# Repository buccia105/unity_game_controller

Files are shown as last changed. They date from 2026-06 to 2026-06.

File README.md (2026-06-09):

# Unity Game Controller (Hardware Firmware)

This project contains the firmware for a physical game controller based on a microcontroller (ESP32/ESP8266), developed using **PlatformIO**. The device is designed to send input signals to a Unity application via network or serial protocol.

## Tech Stack
*   **Framework:** Arduino / PlatformIO 
*   **Supported Hardware:** ESP32 / ESP8266 
*   **Language:** C++ (C# on the Unity side) 

## Project Structure
*   `src/main.cpp`: Main firmware logic and physical input management.
*   `include/credentials.h`: Wi-Fi credentials configuration (do not publish!).
*   `platformio.ini`: Build environment and library configuration.
*   `lib/`: Local libraries specific to the controller.
*   `PCB/`: Files needed to create the pcb.
*   `SHOE/`: Files needed to print the shoe.

## Setup and Installation

### 1. Prerequisites
Ensure you have [Visual Studio Code](https://code.visualstudio.com/) installed with the **PlatformIO IDE** extension.

### 2. Credentials Management
The project uses a protection system for sensitive credentials:
1. Rename the file `include/template_credentials.h` to `include/credentials.h`.
2. Enter your Wi-Fi SSID and Password inside the file.
   *(Note: `credentials.h` is already included in `.gitignore` for security purposes)*.

### 3. Build and Upload
1. Connect the microcontroller to your computer via USB.
2. Click the arrow icon (→) in the PlatformIO status bar to compile and upload the code to the board.

## How it Works
The controller reads data from sensors or buttons connected to the microcontroller pins and packages them to be received by Unity. Make sure the controller's IP address and the PC running Unity are on the same subnet.

## Hardware:
### PCB:
In the `PCB/` directory there are all the files needed to send to the pcb manufacturer, the schematics will help you build the hardware to test the controller, everything is already set up, just connect everything and flash the ESP32.

* remember to solder 2 wires on `D0` and `D1` pins to be able to send a "reset" command via osc via pin `D1`, and calibrate the ADXL375 with the pin `D0`.

* the screen is from waveshare [Link](https://www.waveshare.com/1.54inch-lcd-module.htm).

### SHOE:
The shoe has been modified in Blender and Fusion360, so the size is fixed to 43EU, changing the size on the slicer or other software will end up breaking the dimentions for the hardware. The files should be printed as follows:

* `SHOE_modified.stl`: needs to be printed in TPU95A, my suggetion is with support enabled, it will be a pain to remove them but the final result will be worth.
* `electronics_boxes.step`: should be printed with PLA/PETG/ABS, a solid material to avoid mechanically stressing the electronics, enable supports only where is needed, like on the overhangs for the connectors holes.

## Video tour (fully assembled)
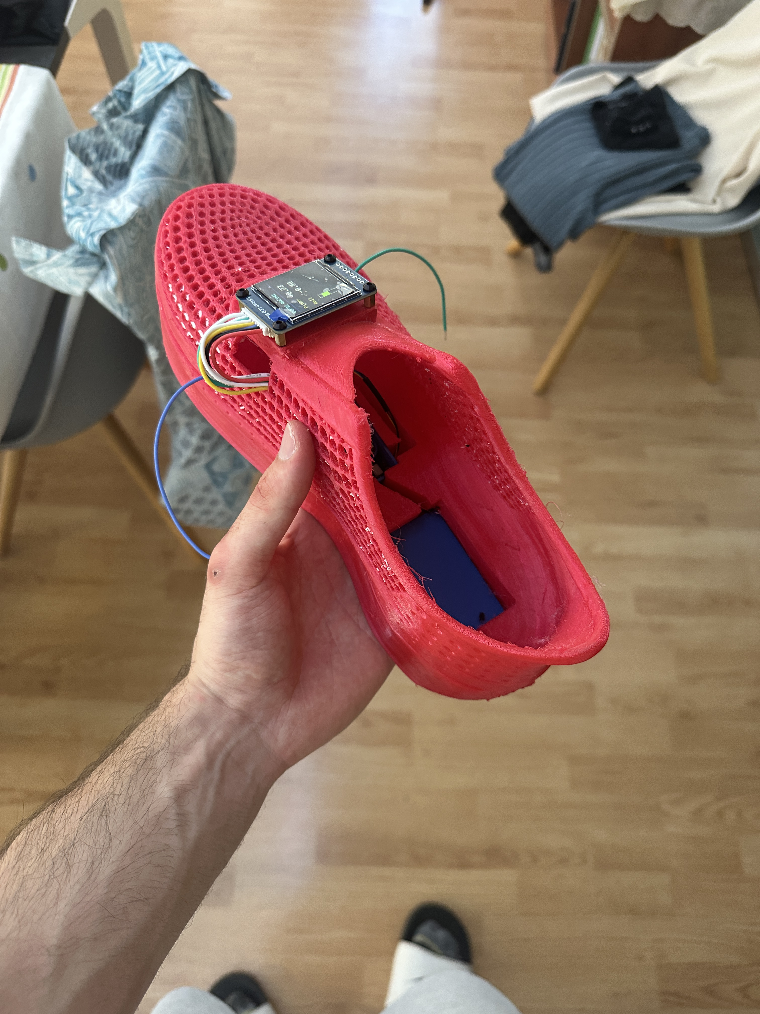
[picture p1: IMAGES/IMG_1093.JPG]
Tour (https://youtube.com/shorts/1ewApq3uuPU?feature=share)


## Video DEMO
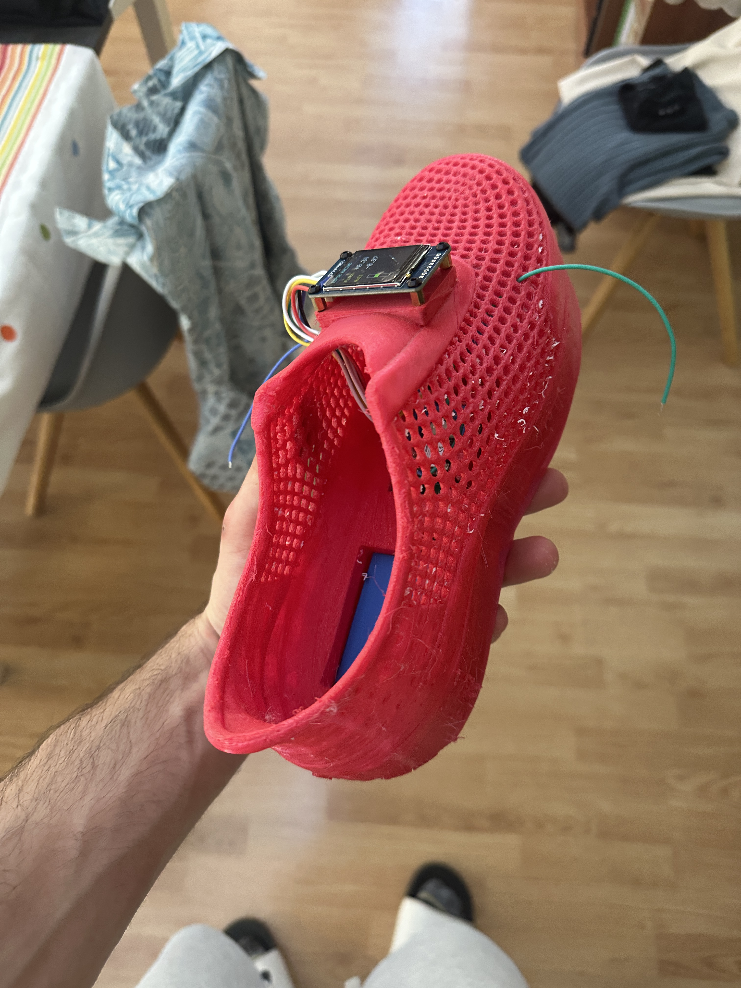
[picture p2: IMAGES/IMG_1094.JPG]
DEMO (https://youtube.com/shorts/eRb2sZXc62k?feature=share)


## 📝 License
Distributed under the GPL-3.0 License. See the `LICENSE` file for details.

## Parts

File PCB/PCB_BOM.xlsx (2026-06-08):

DigiKey - BOM
INDEX | Quantity | DigiKey Code | Manufacturer Code | Description | Unitary Price | Total Price
1 | 1 | 455-SM04B-SRSS-TBCT-ND | SM04B-SRSS-TB | CONN HEADER SMD R/A 4POS 1MM | 0.44 | 0.44
2 | 1 | 455-S8B-PH-SM4-TBCT-ND | S8B-PH-SM4-TB | CONN HEADER SMD R/A 8POS 2MM | 0.74 | 0.74
3 | 1 | SAM1109-32-ND | SL-132-TT-11 | CONN RCPT 32POS 0.1 TIN PCB | 3.8 | 3.80
4 | 1 | SAM1005-32-ND | BBS-132-T-A | CONN HEADER VERT 32POS 2.54MM | 4.15 | 4.15
5 | 1 | 455-1189-ND | PHR-8 | CONN RCPT HSG 8POS 2.00MM | 0.09 | 0.09
6 | 100 | 455-1318-100-ND | SPH-004T-P0.5S | CONN SOCKET 28-32AWG CRIMP TIN | 0.0338 | 3.38
7 | 1 | 1528-4210-ND | 4210 | JST SH 4-PIN CABLE - QWIIC COMPA | 0.81 | 0.81
8 | 1 | 1528-5374-ND | 5374 | STEMMA QT ADXL375 I2C/SPI ACCEL | 21.37 | 21.37

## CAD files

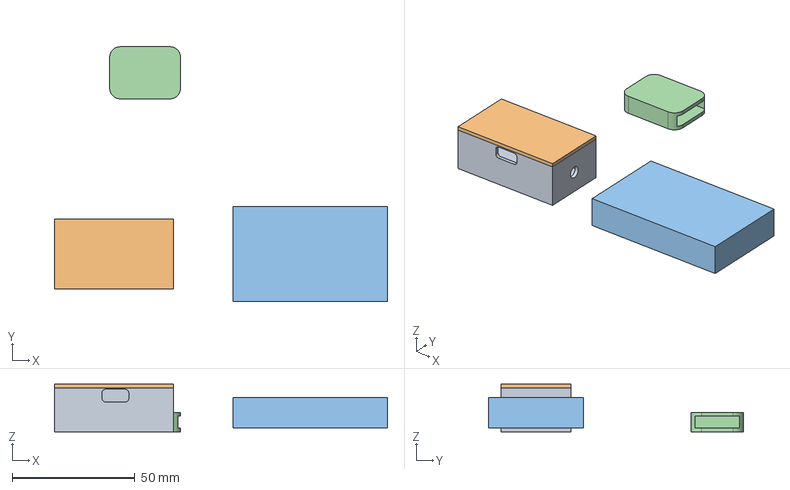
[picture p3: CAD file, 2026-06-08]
SHOE/electronics_boxes.step
135.8 x 103.8 x 19.5 mm

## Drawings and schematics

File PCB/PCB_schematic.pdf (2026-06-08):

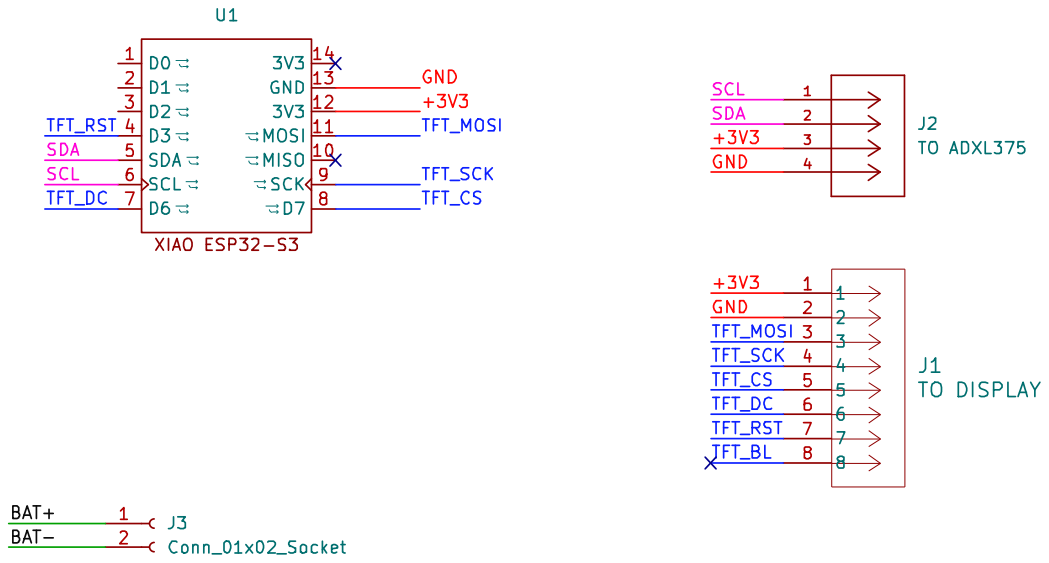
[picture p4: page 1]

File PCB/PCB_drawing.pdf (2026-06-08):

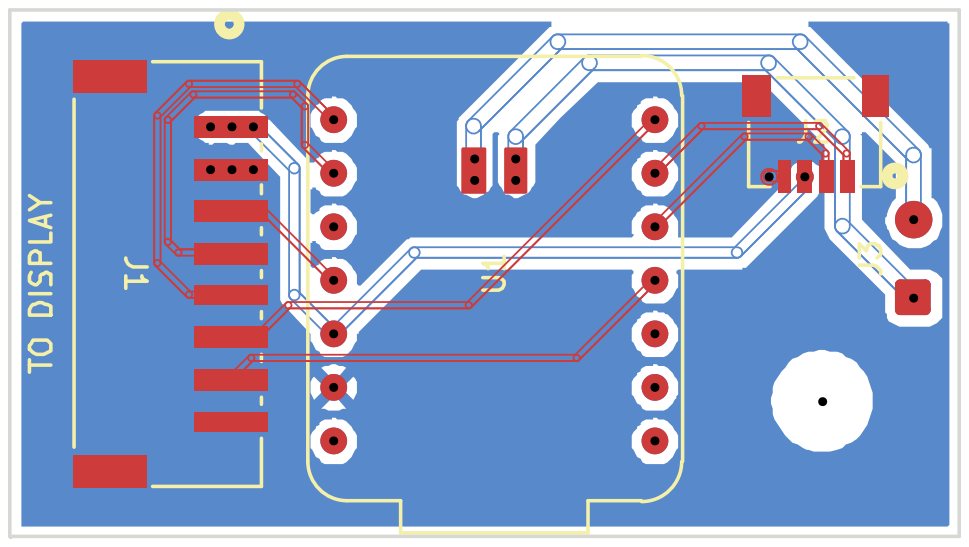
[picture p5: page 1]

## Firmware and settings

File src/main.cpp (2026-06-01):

#include <Arduino.h>
#include "Display.h"
#include "OSC.h"

void setup() {
    Serial.begin(115200);
    
    // starting the screen
    initDisplay();

    // starting wi-fi and getting a response
    if (!initOSC()) {
        showSensorError();
        while(1); 
    }

    // showing wi-fi status
    showWiFiStatus(true);
}

void loop() {

    // timing variable
    unsigned long currentMillis = millis();

    // variables coming from osc functions
    float pitch = 0.0f;
    float roll = 0.0f;
    bool justCalibrated = false;
    bool resetJustNow = false;

    // running osc and sensor logic
    // returns true if enough time has passed and we are ready to fetch data
    if (processOSC(currentMillis, pitch, roll, justCalibrated, resetJustNow)) {
        // redraw new values if there is new data
        updateDisplayValues(pitch, roll);
    }

    // showing if the accellerometer was just calibrated
    if (justCalibrated) {
        showCalibrationMessage(currentMillis);
    }

    // display cleanup
    handleDisplayTasks(currentMillis);
}
